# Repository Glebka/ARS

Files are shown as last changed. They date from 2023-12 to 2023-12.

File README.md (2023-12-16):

# ARS - Alarm System

My first project based on the STM32 microcontroller family. It consists of an alarm module and a receiver. The alarm module utilizes the RCWL-0516 motion sensor, the STM32F030K6T6 microcontroller, which wakes up upon interruption from the sensor, and communicates the alarm using the LoRa module RA-02 at 433 MHz.

As the receiver, an ESP32 TTGO LoRa 433MHz development board with an OLED display is used. The receiver spends most of its time in a sleeping state to reduce power consumption. Upon receiving an alarm signal, the receiver wakes up, displays a text status on the screen, and activates an LED indicator. The LED continues to blink even in sleep mode until the user resets the alarm state. This is made possible by the ULP coprocessor.

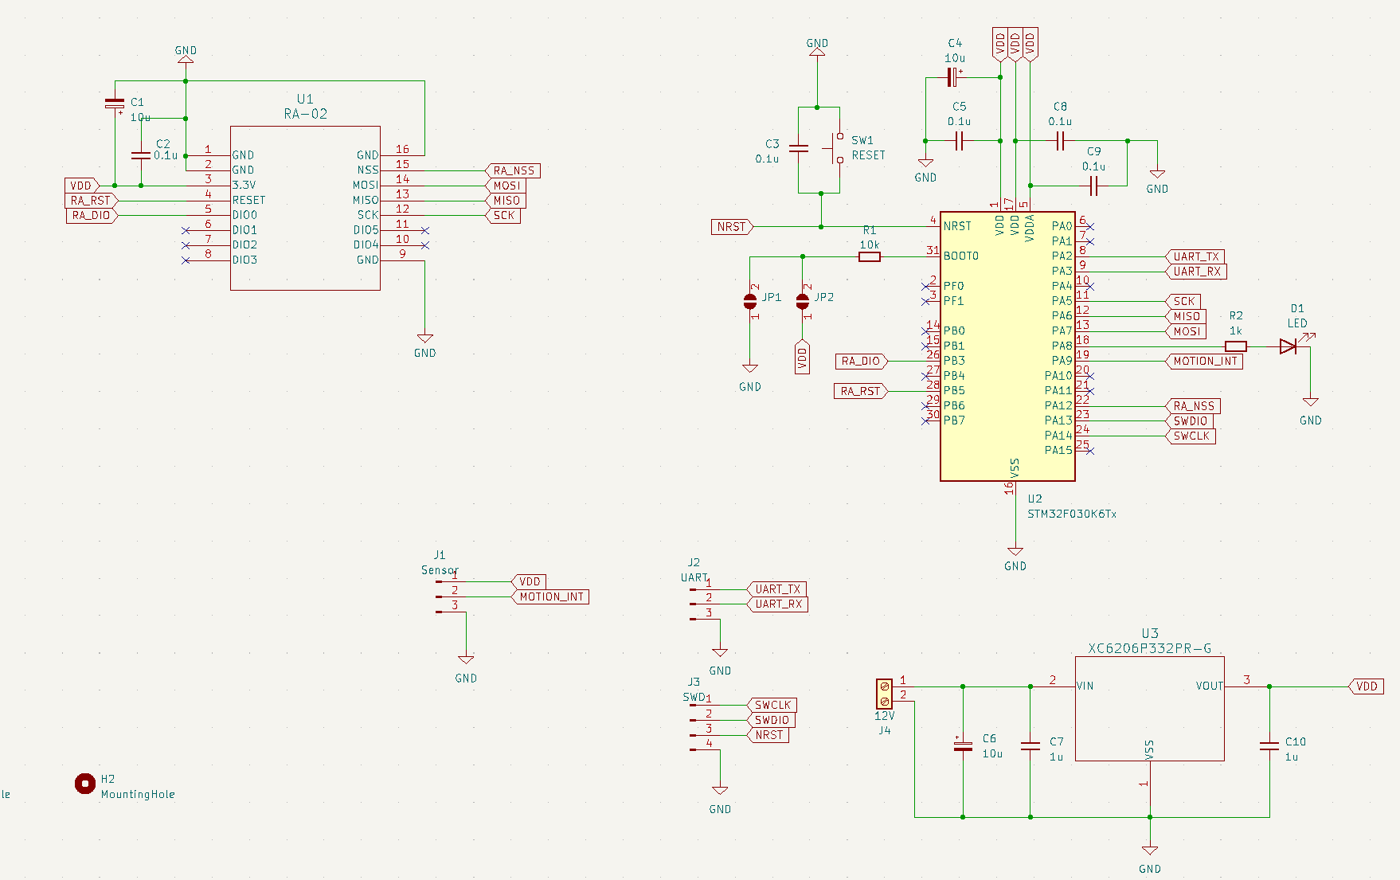
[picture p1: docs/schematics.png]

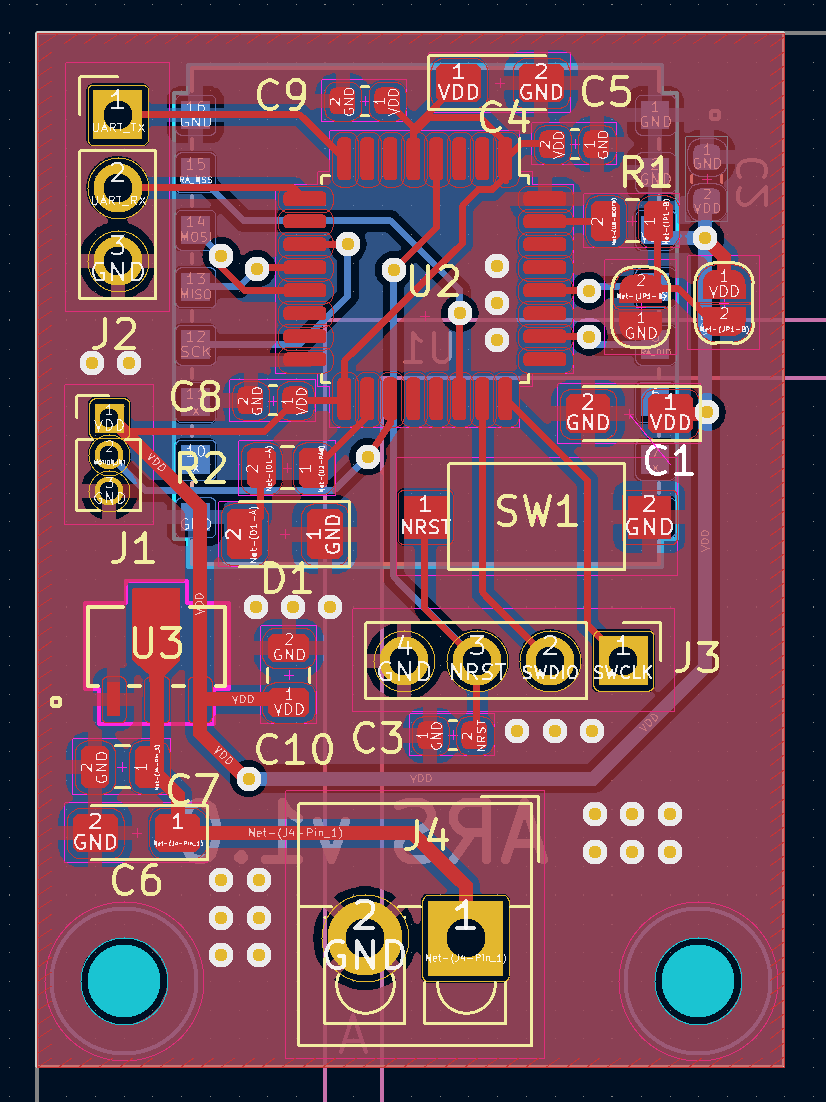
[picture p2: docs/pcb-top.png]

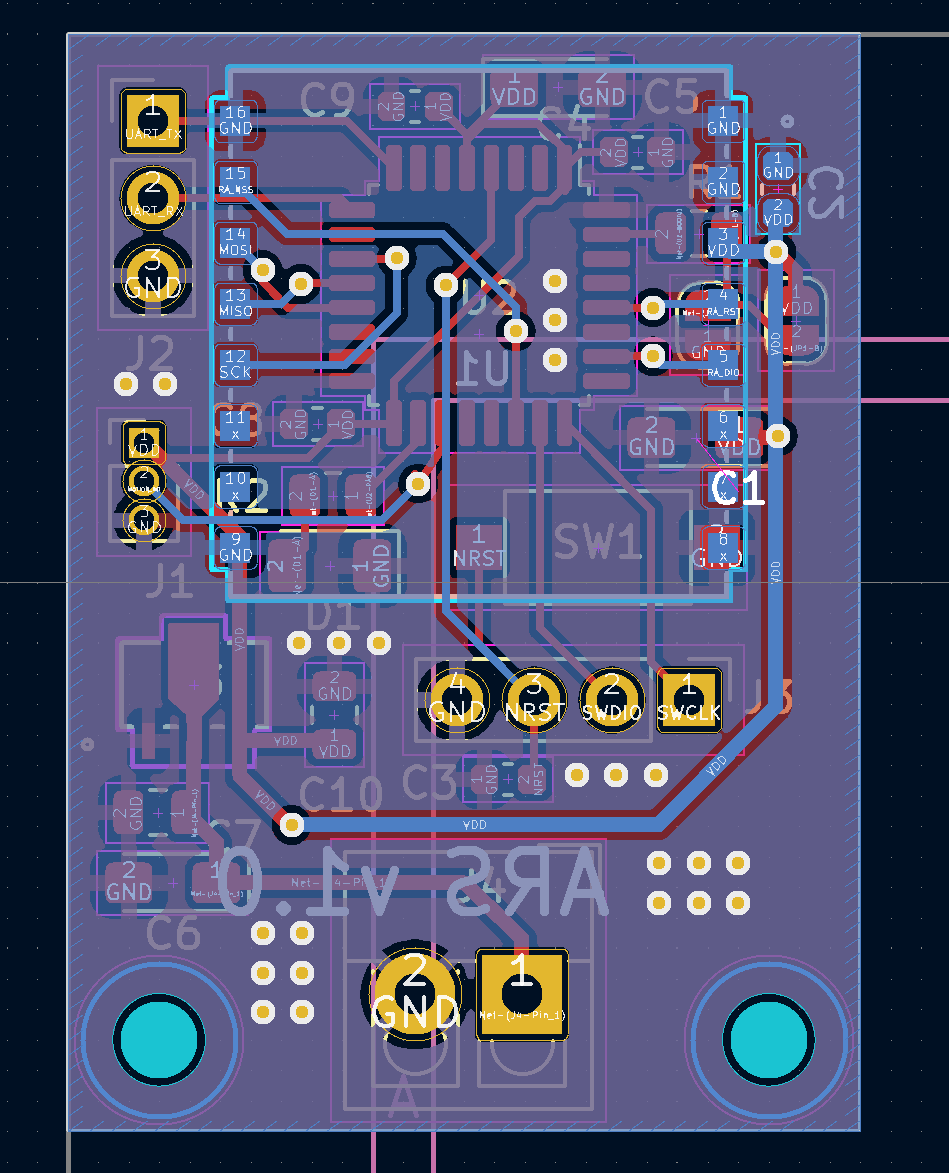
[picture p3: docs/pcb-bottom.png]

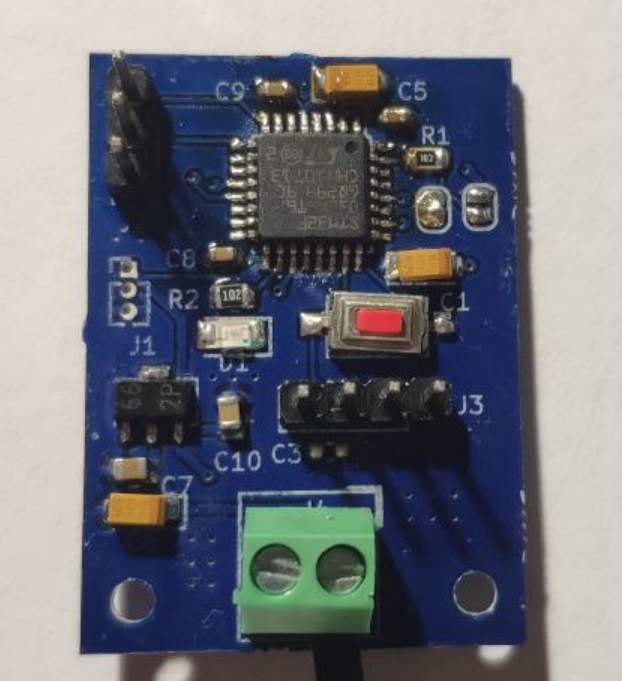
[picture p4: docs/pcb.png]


## TODO

- Configure the alarm module to operate on battery power.
- Implement a buzzer on the receiver to provide an audible signal in case of an alarm.
- Redesign the enclosure for the receiver.
- Design an enclosure for the alarm module.
- Add encryption
- Add protection from replay attacks

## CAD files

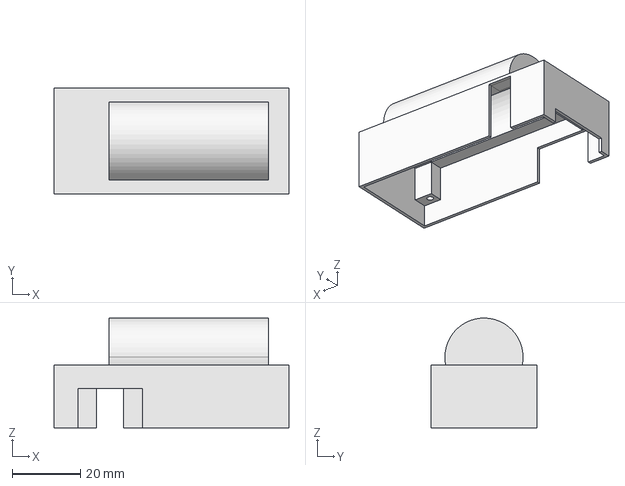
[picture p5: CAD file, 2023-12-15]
cad/ttgo/ttgo.FCStd
69.1 x 31.1 x 32.3 mm

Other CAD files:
cad/ttgo/ttgo-Body.stl

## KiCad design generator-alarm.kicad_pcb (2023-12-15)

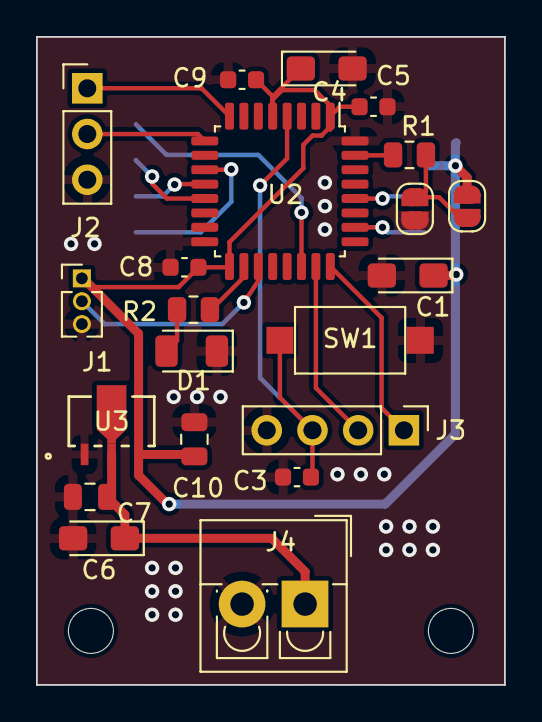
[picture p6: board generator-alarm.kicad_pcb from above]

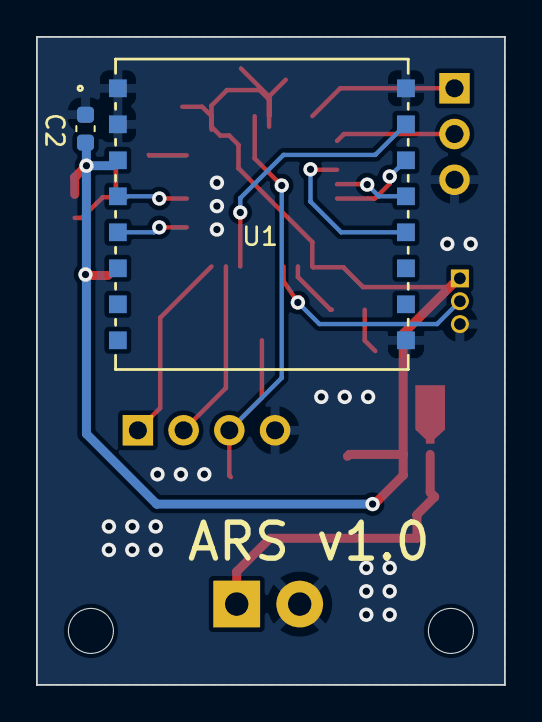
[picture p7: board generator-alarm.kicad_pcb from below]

Board: 2 copper layers, 26.0 x 36.0 mm, 25 parts (2 on the bottom side), 19 nets.

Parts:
C1, C4, C6: 10u; CP_EIA-3216-10_Kemet-I_Pad1.58x1.35mm_HandSolder
C2, C3, C5, C8, C9: 0.1u; C_0603_1608Metric
C7, C10: 1u; C_0805_2012Metric
D1: LED; LED_1206_3216Metric
H1, H2: MountingHole; MountingHole_2.5mm
J1: Sensor; PinHeader_1x03_P1.27mm_Vertical
J2: UART; PinHeader_1x03_P2.54mm_Vertical
J3: SWD; PinHeader_1x04_P2.54mm_Vertical
J4: 12V; TerminalBlock_4Ucon_1x02_P3.50mm_Vertical
JP1, JP2: SolderJumper_2_Open; SolderJumper-2_P1.3mm_Open_RoundedPad1.0x1.5mm
R1: 10k; R_0805_2012Metric
R2: 1k; R_0805_2012Metric
SW1: RESET; SW_SPST_CK_RS282G05A3
U1: RA-02; RA-02_AIT
U2: STM32F030K6Tx; LQFP-32_7x7mm_P0.8mm
U3: XC6206P332PR-G; SOT-89_TOR

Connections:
GND: C1.2, C2.1, C3.1, C4.2, C5.1, C6.2, C7.2, C8.2, C9.2, C10.2, D1.1 (K), J1.3, J2.3, J3.4, J4.2, JP1.1 (A), SW1.2, U1.1 (GND), U1.2 (GND), U1.9 (GND), U1.16 (GND), U2.16 (VSS), U2.32 (VSS), U3.1 (VSS)
MISO: U1.13 (MISO), U2.12 (PA6)
MOSI: U1.14 (MOSI), U2.13 (PA7)
MOTION_INT: J1.2, U2.19 (PA9)
NRST: C3.2, J3.3, SW1.1, U2.4 (NRST)
unnamed: D1.2 (A), R2.2
unnamed: C6.1, C7.1, J4.1, U3.2 (VIN)
unnamed: JP1.2 (B), JP2.2 (B), R1.1
unnamed: R1.2, U2.31 (BOOT0)
unnamed: R2.1, U2.18 (PA8)
RA_DIO: U1.5 (DIO0), U2.26 (PB3)
RA_NSS: U1.15 (NSS), U2.22 (PA12)
RA_RST: U1.4 (RESET), U2.28 (PB5)
SCK: U1.12 (SCK), U2.11 (PA5)
SWCLK: J3.1, U2.24 (PA14)
SWDIO: J3.2, U2.23 (PA13)
UART_RX: J2.2, U2.9 (PA3)
UART_TX: J2.1, U2.8 (PA2)
VDD: C1.1, C2.2, C4.1, C5.2, C8.1, C9.1, C10.1, J1.1, JP2.1 (A), U1.3 (3.3V), U2.1 (VDD), U2.5 (VDDA), U2.17 (VDD), U3.3 (VOUT)

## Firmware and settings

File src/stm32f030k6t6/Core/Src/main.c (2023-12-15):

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
/* Includes ------------------------------------------------------------------*/
#include "main.h"

/* USER CODE BEGIN Includes */
#include <stdio.h>
#include <string.h>
#include <stdlib.h>
#include <LoRa.h>
/* USER CODE END Includes */

/* USER CODE BEGIN PTD */
typedef struct LoRaMessage_t
{
  uint8_t header;
  uint8_t cmd;
  uint8_t cnt;
  int32_t seed;
  uint8_t reserved;
} LoRaMessage;

enum CommandType
{
  CMD_PING,
  CMD_ALERT,
};

enum InterruptReason
{
  IRQ_NO_REASON,
  IRQ_MOTION,
  IRQ_PING,
};

/* USER CODE END PTD */

/* USER CODE BEGIN PD */
#define DEFAULT_HEADER 0x77
/* USER CODE END PD */

SPI_HandleTypeDef hspi1;

UART_HandleTypeDef huart1;

/* USER CODE BEGIN PV */
LoRa lora;
volatile uint8_t interrupt_reason = IRQ_NO_REASON;
/* USER CODE END PV */

void SystemClock_Config(void);
static void MX_GPIO_Init(void);
static void MX_SPI1_Init(void);
static void MX_USART1_UART_Init(void);
/* USER CODE BEGIN 0 */
void uart_log(char *msg)
{
  HAL_UART_Transmit(&huart1, (uint8_t *)msg, strlen(msg), HAL_MAX_DELAY);
}

void enter_stop_mode()
{
  HAL_SuspendTick();
  HAL_PWR_EnterSTOPMode(PWR_LOWPOWERREGULATOR_ON, PWR_STOPENTRY_WFI);
}

void exit_stop_mode()
{
  SystemClock_Config();
  HAL_ResumeTick();
}

void enter_sleep_mode()
{
  HAL_SuspendTick();
  HAL_PWR_EnterSLEEPMode(PWR_MAINREGULATOR_ON, PWR_SLEEPENTRY_WFI);
}

void exit_sleep_mode()
{
  HAL_ResumeTick();
}

LoRaMessage prepare_lora_message(uint8_t cmd)
{
  LoRaMessage msg;
  msg.header = DEFAULT_HEADER;
  msg.seed = rand();
  msg.cnt = 0;
  msg.cmd = cmd;
  msg.reserved = 0;
  return msg;
}

uint8_t transmit_lora_message(LoRaMessage *msg, uint8_t cnt)
{
  uint8_t result = 1;
  for (uint8_t i = 0; i < cnt; i++)
  {
    msg->cnt = i;
    result = LoRa_transmit(&lora, (uint8_t *)msg, sizeof(LoRaMessage), 500);
  }
  return result;
}

/* USER CODE END 0 */

/**
 * @brief  The application entry point.
 * @retval int
 */
int main(void)
{
  /* MCU Configuration--------------------------------------------------------*/

  /* Reset of all peripherals, Initializes the Flash interface and the Systick. */
  HAL_Init();

  /* Configure the system clock */
  SystemClock_Config();

  /* Initialize all configured peripherals */
  MX_GPIO_Init();
  MX_SPI1_Init();
  MX_USART1_UART_Init();
  /* USER CODE BEGIN 2 */
  uart_log("\r\nARS v1.0\r\n");
  uart_log("Initializing LoRa module...\r\n");
  lora = newLoRa();
  lora.hSPIx = &hspi1;
  lora.CS_port = RA_NSS_GPIO_Port;
  lora.CS_pin = RA_NSS_Pin;
  lora.reset_port = RA_RST_GPIO_Port;
  lora.reset_pin = RA_RST_Pin;
  lora.DIO0_port = RA_DIO0_GPIO_Port;
  lora.DIO0_pin = RA_DIO0_Pin;

  LoRa_reset(&lora);
  uint16_t lora_init_result = LoRa_init(&lora);
  if (lora_init_result != LORA_OK)
  {
    char msg_buf[50];
    sprintf(msg_buf, "LoRa init error 0x%X\r\n", lora_init_result);
    uart_log(msg_buf);
    Error_Handler();
  }
  uart_log("LoRa initialized\r\n");
  /* USER CODE END 2 */

  /* Infinite loop */
  /* USER CODE BEGIN WHILE */
  while (1)
  {
    switch (interrupt_reason)
    {
    case IRQ_MOTION:
    {
      LoRaMessage msg = prepare_lora_message(CMD_ALERT);
      if (!transmit_lora_message(&msg, 5))
      {
        uart_log("Transmit timeout error\r\n");
      }
      uart_log("Motion detected, alert sent\r\n");
      break;
    }
    case IRQ_PING:
    default:
    {
      LoRaMessage msg = prepare_lora_message(CMD_PING);
      if (!transmit_lora_message(&msg, 5))
      {
        uart_log("Transmit timeout error\r\n");
      }
      uart_log("PING sent\r\n");
      break;
    }
    }
    interrupt_reason = IRQ_NO_REASON;
    enter_stop_mode();
    /* USER CODE END WHILE */

    /* USER CODE BEGIN 3 */
  }
  /* USER CODE END 3 */
}

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
/* USER CODE BEGIN 4 */
void HAL_GPIO_EXTI_Callback(uint16_t GPIO_Pin)
{
  exit_stop_mode();
  switch (GPIO_Pin)
  {
  case RA_DIO0_Pin:
    /* code */
    break;
  case MOTION_INT_Pin:
    interrupt_reason = IRQ_MOTION;
    break;
  default:
    break;
  }
}

/* USER CODE END 4 */
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


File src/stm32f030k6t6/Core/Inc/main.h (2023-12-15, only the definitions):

#define STATUS_LED_Pin GPIO_PIN_8
#define STATUS_LED_GPIO_Port GPIOA
#define MOTION_INT_Pin GPIO_PIN_9
#define MOTION_INT_GPIO_Port GPIOA
#define MOTION_INT_EXTI_IRQn EXTI4_15_IRQn
#define RA_NSS_Pin GPIO_PIN_12
#define RA_NSS_GPIO_Port GPIOA
#define RA_DIO0_Pin GPIO_PIN_3
#define RA_DIO0_GPIO_Port GPIOB
#define RA_RST_Pin GPIO_PIN_5
#define RA_RST_GPIO_Port GPIOB

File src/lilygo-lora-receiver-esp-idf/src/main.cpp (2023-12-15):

#include <stdio.h>
#include <string.h>
#include <inttypes.h>
#include "esp_sleep.h"
#include "soc/rtc_cntl_reg.h"
#include "soc/sens_reg.h"
#include "soc/rtc_periph.h"
#include "driver/gpio.h"
#include "driver/rtc_io.h"
#include "esp32/ulp.h"
#include "ulp_main.h"
#include <freertos/FreeRTOS.h>
#include <freertos/task.h>
#include "sdkconfig.h"
#include <Arduino.h>
#include <SPI.h>
#include <LoRa.h>
#include <SSD1306.h>

#define SCK GPIO_NUM_5   // GPIO5  -- SX1278's SCK
#define MISO GPIO_NUM_19 // GPIO19 -- SX1278's MISO
#define MOSI GPIO_NUM_27 // GPIO27 -- SX1278's MOSI
#define SS GPIO_NUM_18   // GPIO18 -- SX1278's CS
#define RST GPIO_NUM_23  // GPIO14 -- SX1278's RESET
#define DI0 GPIO_NUM_26  // GPIO26 -- SX1278's IRQ(Interrupt Request)
#define LED GPIO_NUM_25
#define SDA GPIO_NUM_21
#define SCL GPIO_NUM_22
#define BAND 433E6
#define DEFAULT_HEADER 0x77
#define LED_BLINK_INTERVAL 1000
#define ENTER_SLEEP_TIMEOUT 10000

extern const uint8_t ulp_main_bin_start[] asm("_binary_ulp_main_bin_start");
extern const uint8_t ulp_main_bin_end[] asm("_binary_ulp_main_bin_end");

static void init_ulp_program(void);
static void start_ulp_program(void);

typedef struct LoRaMessage_t
{
    uint8_t header;
    uint8_t cmd;
    uint8_t cnt;
    int32_t seed;
    uint8_t reserved;
} LoRaMessage;

enum CommandType
{
    CMD_PING,
    CMD_ALERT,
};

SSD1306 display(0x3c, SDA, SCL);

volatile bool packet_available = false;
int32_t last_seed = 0;
LoRaMessage last_message;

TimerHandle_t SleepTimerHandle = NULL;

void on_lora_received(int _)
{
    packet_available = true;
}

void init_lora()
{
    SPI.begin(SCK, MISO, MOSI, SS);
    LoRa.setPins(SS, RST, DI0);
    if (!LoRa.begin(BAND))
    {
        printf("Failed to init LoRa\n");
        while (1)
            ;
    }
    LoRa.onReceive(on_lora_received);
    gpio_wakeup_enable(DI0, GPIO_INTR_HIGH_LEVEL);
    esp_sleep_enable_gpio_wakeup();
    LoRa.receive();
}

void init_display()
{
    display.init();
    display.flipScreenVertically();
    display.setFont(ArialMT_Plain_10);
    display.clear();
}

void update_display()
{
    display.displayOn();
    display.clear();
    display.setTextAlignment(TEXT_ALIGN_LEFT);
    display.setFont(ArialMT_Plain_10);
    display.drawString(0, 0, "Received " + String(ulp_alerts_received, DEC) + " alerts");
    display.display();
}

void enter_light_sleep_mode(TimerHandle_t timer)
{
    display.clear();
    display.displayOff();
    xTimerDelete(SleepTimerHandle, 0);
    SleepTimerHandle = NULL;
    esp_light_sleep_start();
}

void schedule_sleep()
{
    if (SleepTimerHandle == NULL)
    {
        SleepTimerHandle = xTimerCreate("SLEEP_TIMER",
                                        (ENTER_SLEEP_TIMEOUT),
                                        pdFALSE,
                                        NULL,                                           /* The ID is used, as the LED number so set it to that. */
                                        (TimerCallbackFunction_t)enter_light_sleep_mode /* The callback function that inspects the status of all the other tasks. */
        );
        if (SleepTimerHandle == NULL)
        {
            printf("Failed to create sleep timer!\n");
            return;
        }
        if (xTimerStart(SleepTimerHandle, 0) != pdPASS)
        {
            printf("The timer could not be set into the Active state.\n");
        }
    }
}

void reset_sleep_timer()
{
    if (SleepTimerHandle != NULL)
    {
        xTimerReset(SleepTimerHandle, 0);
    }
}

void setup()
{
    Serial.begin(115200);
    while (!Serial)
        ;
    Serial.println();

    rtc_gpio_init(LED);
    rtc_gpio_set_direction(LED, RTC_GPIO_MODE_OUTPUT_ONLY);
    rtc_gpio_set_level(LED, 0);

    init_lora();
    init_display();
    init_ulp_program();
    start_ulp_program();
    update_display();
}

void loop()
{
    if (packet_available)
    {
        packet_available = false;
        while (LoRa.available() > 0)
        {
            printf("Available to read from LoRa: %d bytes\n", LoRa.available());
            size_t bytes_read = LoRa.readBytes((uint8_t *)&last_message, sizeof(LoRaMessage));
            if (bytes_read == sizeof(LoRaMessage) && last_message.header == DEFAULT_HEADER && last_message.cmd == CMD_ALERT && last_message.seed != last_seed)
            {
                last_seed = last_message.seed;
                ulp_alerts_received++;
                printf("Msg: cmd=0x%x, cnt=%d, seed=0x%x\n", last_message.cmd, last_message.cnt, last_message.seed);
                update_display();
            }
        }
        reset_sleep_timer();
    }
    schedule_sleep();
    delay(100);
}

static void init_ulp_program(void)
{
    esp_err_t err = ulp_load_binary(0, ulp_main_bin_start,
                                    (ulp_main_bin_end - ulp_main_bin_start) / sizeof(uint32_t));
    ESP_ERROR_CHECK(err);

    /* Set ULP wake up period to 1s */
    ulp_set_wakeup_period(0, 1000000);
}

static void start_ulp_program(void)
{
    esp_err_t err = ulp_run(&ulp_entry - RTC_SLOW_MEM);
    ESP_ERROR_CHECK(err);
}

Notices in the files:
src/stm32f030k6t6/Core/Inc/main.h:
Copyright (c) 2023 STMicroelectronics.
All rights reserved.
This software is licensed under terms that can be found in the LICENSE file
